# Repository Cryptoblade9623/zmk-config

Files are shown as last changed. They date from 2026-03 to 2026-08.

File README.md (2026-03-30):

Introduction
This is an ergonomic split keyboard that I designed to match the shape of my hands.
It is designed this way to hopefully reduce strain on my wrists and hands when typing.
I like making stuff.
I also just think that split keyboards are cool.
It uses the Seeeduino XIAO BLE nRF52840.
It has bluetooth communication capabilities and has a USB-C port.

Images

Above is my Split keyboard design on Fusion360.

Above is my PCB design.

Above is the root sheet for the schematics.


Above are the left then right schematics sheets.

Status
I have designed everything (hopefully) like the firmware, PCB and schematics.
I have also created the BOM.
I will start assembly when it is approved and i buy the parts needed.

Assembly instructions
1. Solder the diodes and hall sensors.
2. Solder the male header pins onto the seeeduino.
3. Link the seeeduino to the firmware on ZMK.
4. Solder the other side of the male header pins onto the PCB.
5. Screw the stabilizers into the PCB.
6. Solder the wires of the battery to the bat pins of the microcontroller and the sliding switch.
7. Place the battery into the small cavity in between the case and where the PCb is meant to go.
8. Screw the sliding switch into the side.
9. Insert the brass threaded insert into the 3d printed case in the middle and on the rim by heating the inserts and pushing them in.
10. Screw in the five mounting screw in to the middle.
11. Place the PCB on top and screw the black screws in.
12. Glue the magnets into the holes in the 3d printed case.
13. Click the key Switches into the plate.
14. Screw the plate on the bigger portion of the case.
15. Click the keycaps into place.
16. Repeat for both halves.
17. Pair both the halves together.
18. Test the keyboard.
I have not actually built the keyboard yet.

BOM
Name	                     Purpose	                          Units Total	            Total (USD)    	Distributor
Male header pin row        For soldering Seeeduino to PCB    	1     	                $1.31	          AliExpress
Battery	                   To supply power                   	1	Pair                  $9.18	          AliExpress
Screws                   	 Secure keyboard parts	            1 Pack	                $1.31	          AliExpress
Mounting screws	           Secure PCB in place	              1 Pack	                $0.74	          AliExpress
Threaded insert	           Housing for screws               	1 Pack                	$1.64	          AliExpress
PCB	                       Main circuit board               	1 Pack                	$14.38	        JLCPCB
Diodes	                   Direct current one way            	1 Pack	                $5.57	          AliExpress
Hall sensors	             Magnetic detection 	              3 Packs	                $11.51   	      AliExpress
Magnets                    Connect halves together	          1 Pack                	$1.31         	AliExpress
Sliding Switches           Power On/Off                     	1	Pack                  $5.10          	Amazon
Stabilizers                Support for larger keycaps	        2	                      $4.44	          AliExpress
Key Switches	             Register key strokes	              1 Pack                	$45.27         	AliExpress
Seeeduino (2pcs)         	 Main controllers	                  1 Pair	                $38.42        	AliExpress
Keycaps	                   Key labels	                        1 Set                 	$16.79	        AliExpress

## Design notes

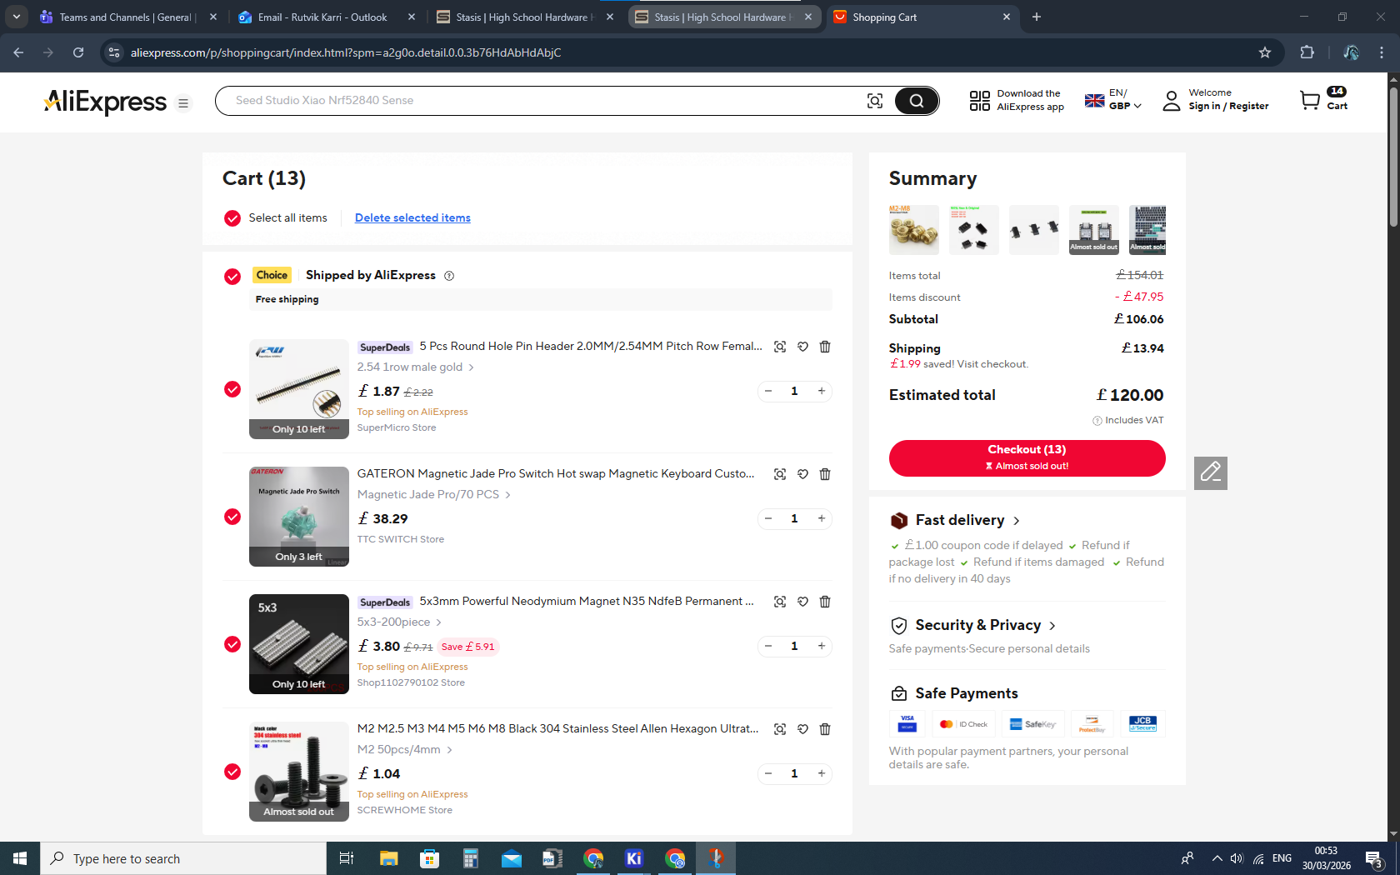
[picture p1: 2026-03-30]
Kicad Files/alicartfinal.png

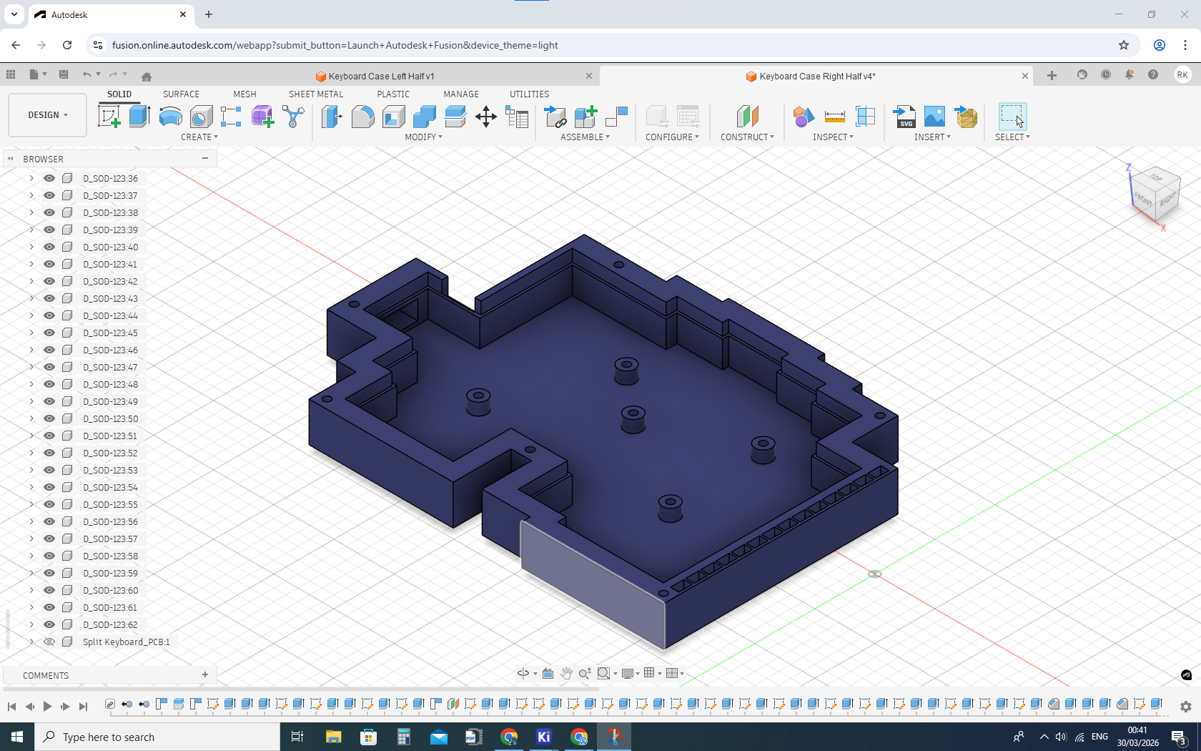
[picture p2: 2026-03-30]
Kicad Files/case right2.png

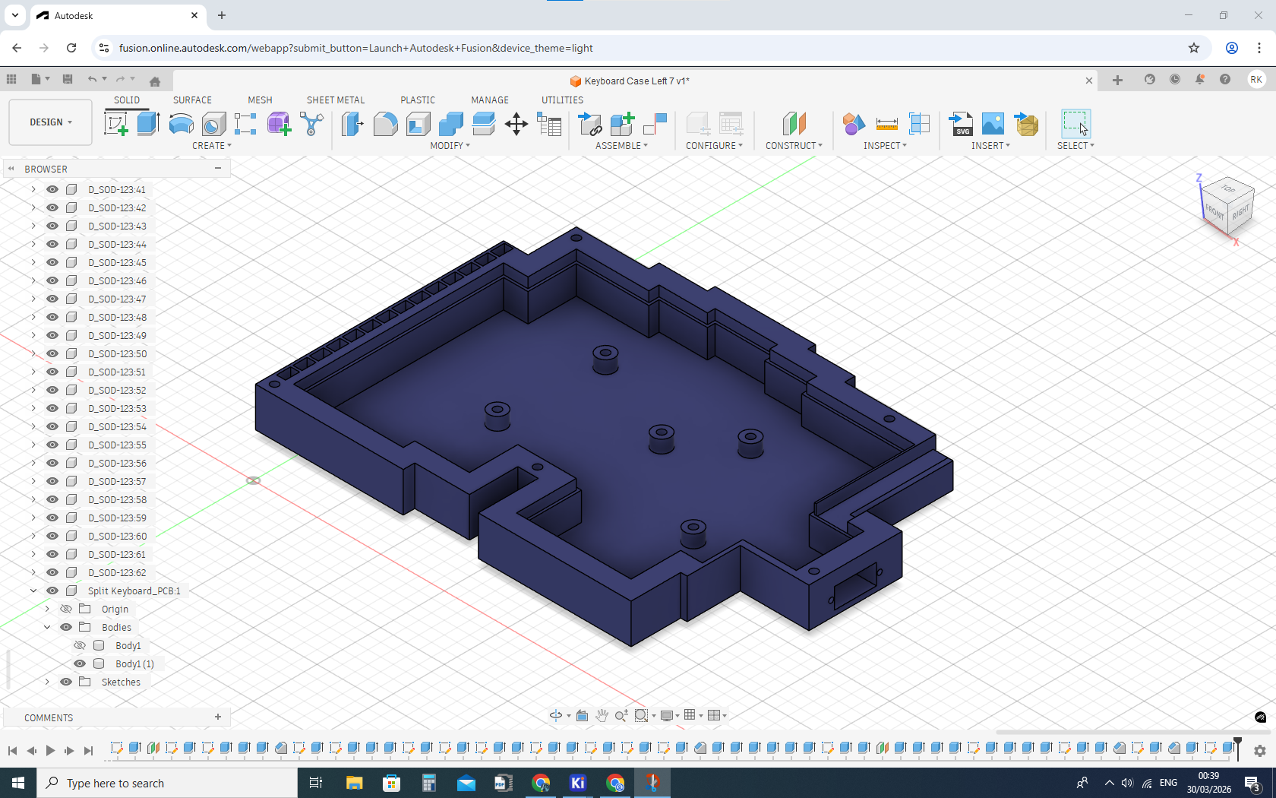
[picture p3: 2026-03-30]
Kicad Files/case left2.png

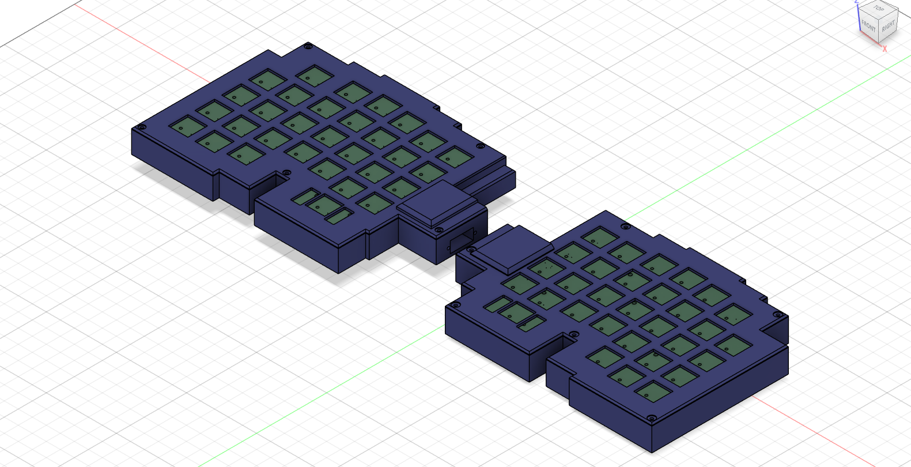
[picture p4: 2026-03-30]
Kicad Files/Both halves split custom keeb.png

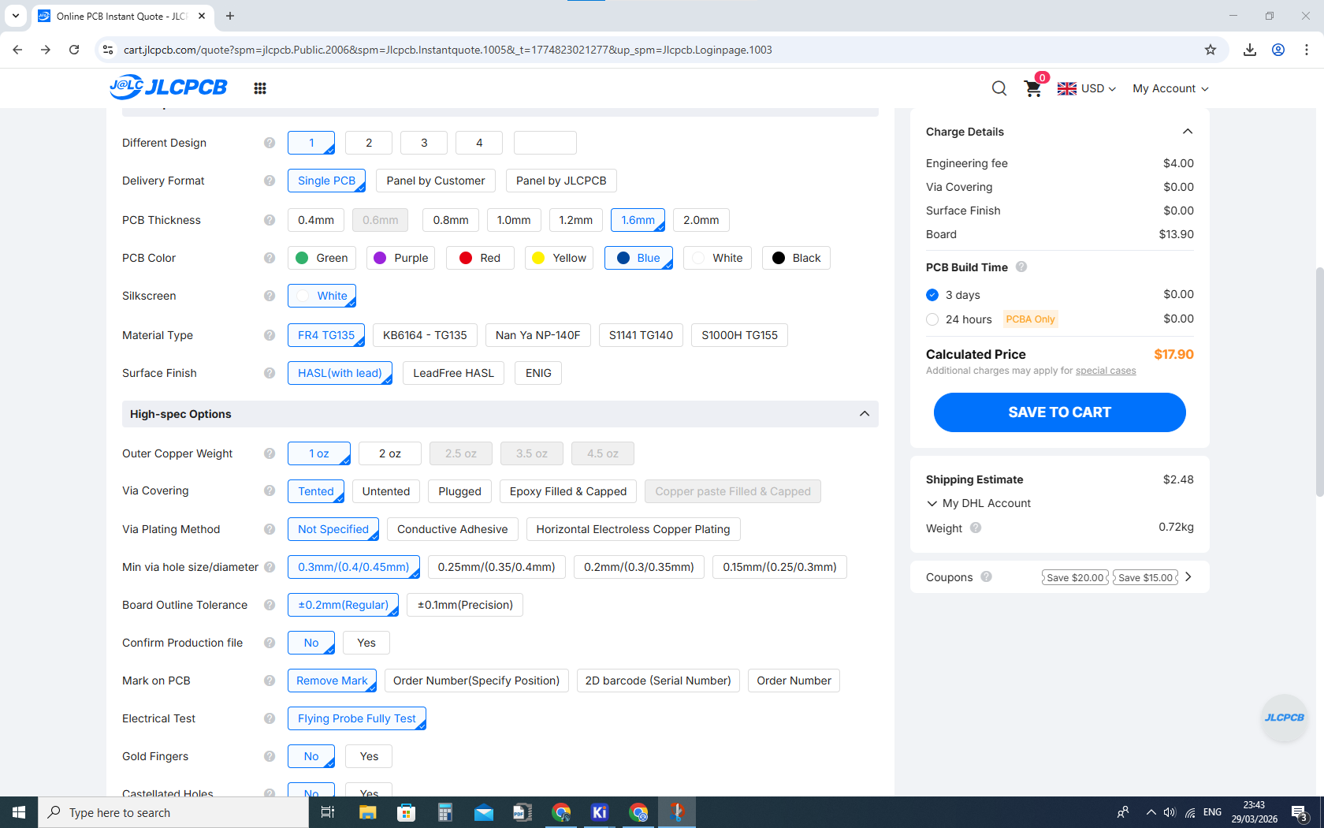
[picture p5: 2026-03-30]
Kicad Files/jlc cart new bottom.png

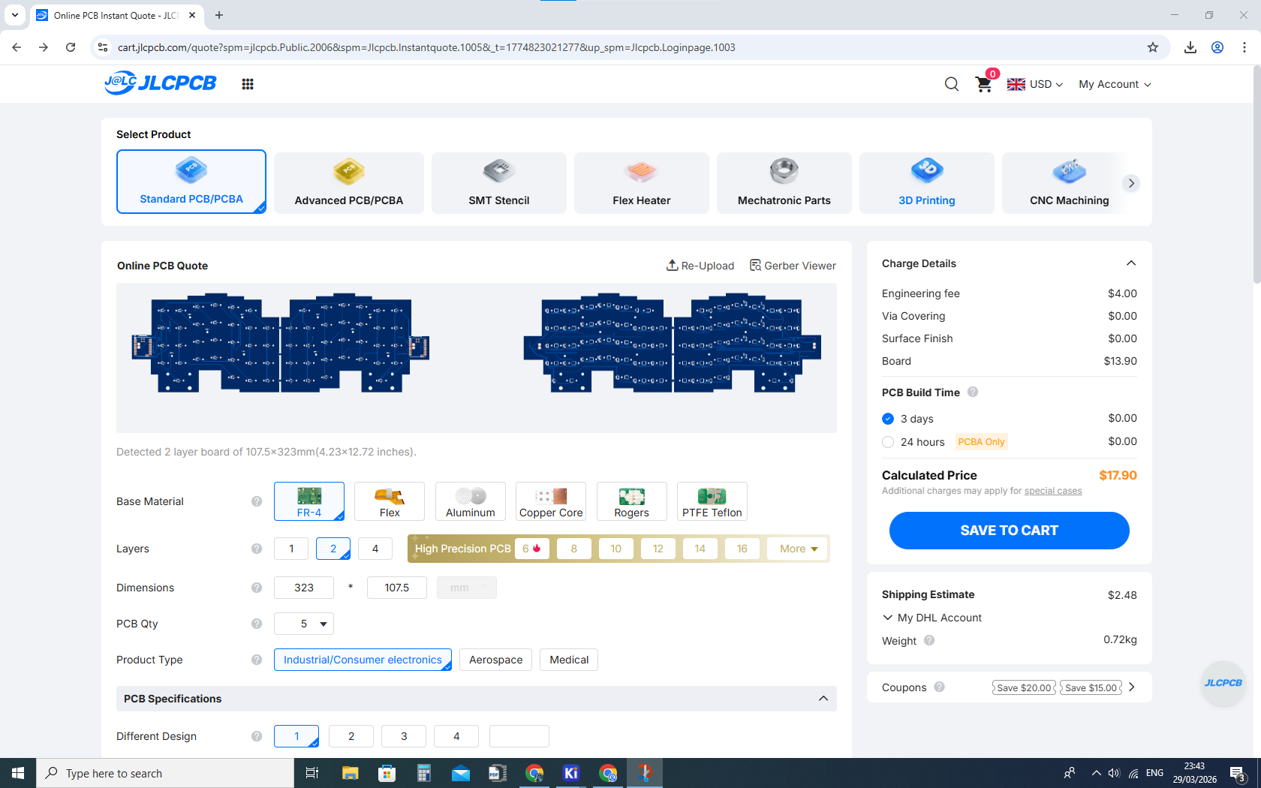
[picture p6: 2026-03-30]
Kicad Files/jlc cart new top.png

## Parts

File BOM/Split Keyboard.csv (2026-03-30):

Reference | Qty | Value | DNP | Exclude from BOM | Exclude from Board | Footprint | Datasheet
D1,D2,D3,D4,D5,D6,D7,D8,D9,D10,D11,D12,D13,D14,D15,D16,D17,D18,D19,D20,D21,D22,D23,D24,D25,D26,D27,D28,D29,D30,D31,D32,D33,D34,D35,D36,D37,D38,D39,D40,D41,D42,D51,D52,D53,D54,D55,D56,D57,D58,D59,D60,D61,D62,D63,D64,D65,D66,D67,D68,D69,D70 | 62 | D |  |  |  | Diode_SMD:D_SOD-123 | ~
H1,H3,H5 | 3 | MountingHole |  | Excluded from BOM |  | Panelization:MouseBite-Slot_2.0x2.0mm_inset_D0.5mm_P0.85mm_4h_Trace | ~
S1,S2 | 2 | MX_stab |  |  |  | marbastlib-mx:STAB_MX_2u
SW1,SW2,SW3,SW4,SW5,SW6,SW7,SW8,SW10,SW11,SW12,SW14,SW15,SW16,SW17,SW18,SW19,SW20,SW21,SW22,SW23,SW24,SW25,SW26,SW27,SW28,SW29,SW30,SW31,SW32,SW33,SW34,SW35,SW36,SW37,SW38,SW39,SW40,SW41,SW42,SW51,SW52,SW53,SW54,SW55,SW56,SW57,SW58,SW59,SW60,SW61,SW62,SW63,SW64,SW65,SW66,SW67,SW68,SW69,SW70 | 60 | SW_Push |  |  |  | marbastlib-he:SW_MX_HE_0deg_1u | ~
SW9,SW13 | 2 | SW_Push |  |  |  | marbastlib-he:SW_MX_HE_0deg_1.5u | ~
U1,U2 | 2 | Seeeduino Xiao nRF52840 |  | Excluded from BOM |  | Modified xioa:modified-XIAO-nRF52840-SMD

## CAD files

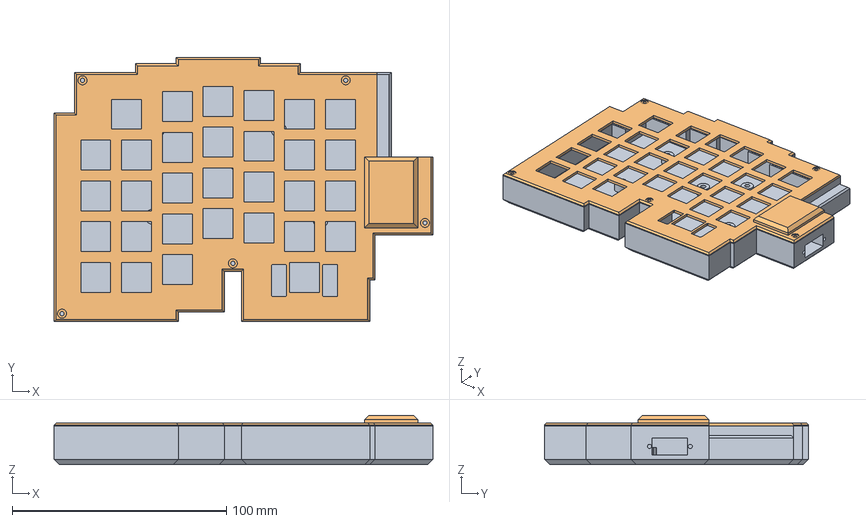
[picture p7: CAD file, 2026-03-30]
Kicad Files/Keyboard Case Left Half.step
177.1 x 123.5 x 23.0 mm
SOT-23 x 60
D_SOD-123 x 62
Split Keyboard_PCB

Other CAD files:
Kicad Files/Keyboard Case Right Half.step
Kicad Files/Keyboard Case Left Half.stl
Kicad Files/Keyboard Case Right Half.stl

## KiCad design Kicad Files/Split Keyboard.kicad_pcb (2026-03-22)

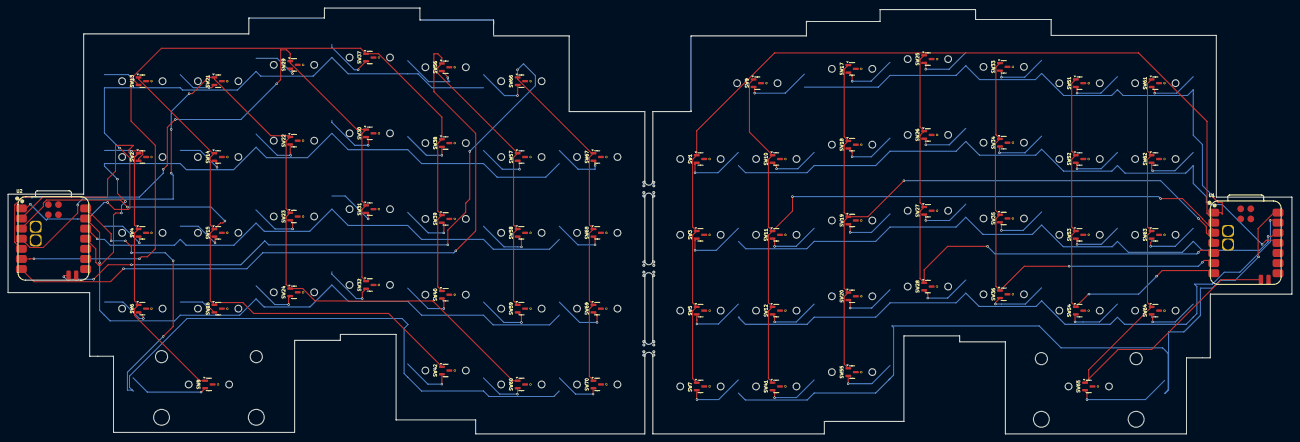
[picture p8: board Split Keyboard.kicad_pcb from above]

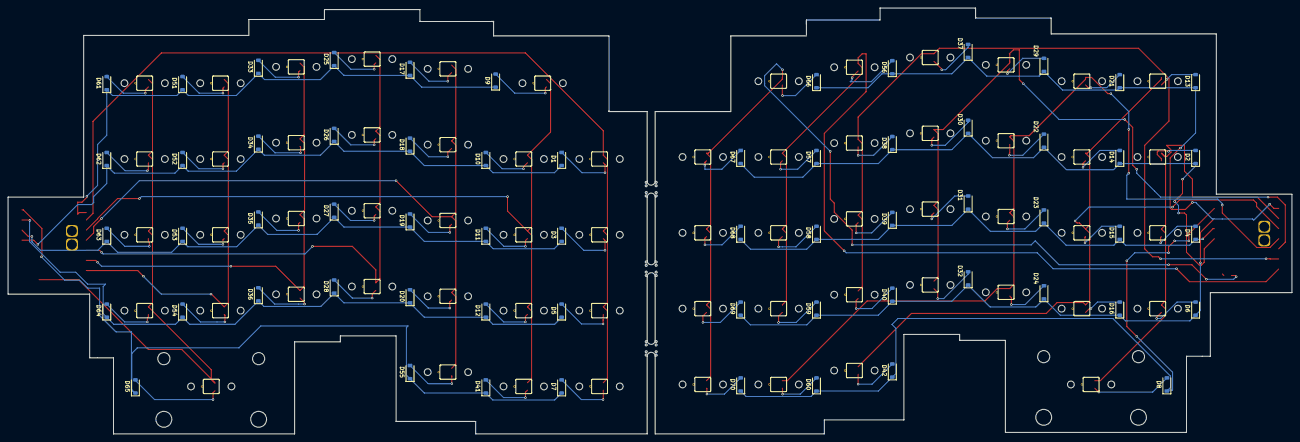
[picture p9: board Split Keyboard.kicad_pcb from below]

Board: 2 copper layers, 322.6 x 107.0 mm, 131 parts (62 on the bottom side), 87 nets.

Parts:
D1, D2, D3, D4, D5, D6, D7, D8, D9, D10, D11, D12, D13, D14, D15, D16, D17, D18, D19, D20, D21, D22, D23, D24, D25, D26, D27, D28, D29, D30, D31, D32, D33, D34, D35, D36, D37, D38, D39, D40, D41, D42, D51, D52, D53, D54, D55, D56, D57, D58, D59, D60, D61, D62, D63, D64, D65, D66, D67, D68, D69, D70: D; D_SOD-123
H1, H3, H5: MountingHole; MouseBite-Slot_2.0x2.0mm_inset_D0.5mm_P0.85mm_4h_Trace
S1, S2: MX_stab; STAB_MX_2u
SW1, SW2, SW3, SW4, SW5, SW6, SW7, SW8, SW10, SW11, SW12, SW14, SW15, SW16, SW17, SW18, SW19, SW20, SW21, SW22, SW23, SW24, SW25, SW26, SW27, SW28, SW29, SW30, SW31, SW32, SW33, SW34, SW35, SW36, SW37, SW38, SW39, SW40, SW41, SW42, SW51, SW52, SW53, SW54, SW55, SW56, SW57, SW58, SW59, SW60, SW61, SW62, SW63, SW64, SW65, SW66, SW67, SW68, SW69, SW70: SW_Push; SW_MX_HE_0deg_1u
SW9, SW13: SW_Push; SW_MX_HE_0deg_1.5u
U1, U2: Seeeduino Xiao nRF52840; modified-XIAO-nRF52840-SMD

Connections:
/Left/COL0: SW1.1, SW3.1, SW5.1, SW7.1, U1.2 (P0.03)
/Left/COL1: SW9.1, SW10.1, SW11.1, SW12.1, SW41.1, U1.3 (P0.28)
/Left/COL2: SW17.1, SW18.1, SW19.1, SW20.1, SW55.1, U1.4 (P0.29)
/Left/COL3: SW25.1, SW26.1, SW27.1, SW28.1, U1.5 (P0.04)
/Left/COL4: SW33.1, SW34.1, SW35.1, SW36.1, U1.6 (P0.05)
/Left/COL5: SW51.1, SW52.1, SW53.1, SW54.1, U1.7 (P1.11)
/Left/COL6: SW61.1, SW62.1, SW63.1, SW64.1, SW65.1, U1.17 (P0.09)
/Left/ROW0: D9.1 (K), D17.1 (K), D25.1 (K), D33.1 (K), D51.1 (K), D61.1 (K), U1.1 (P0.02)
/Left/ROW1: D1.1 (K), D10.1 (K), D18.1 (K), D26.1 (K), D34.1 (K), D52.1 (K), D62.1 (K), U1.11 (P1.15)
/Left/ROW2: D3.1 (K), D11.1 (K), D19.1 (K), D27.1 (K), D35.1 (K), D53.1 (K), D63.1 (K), U1.12 (P1.14)
/Left/ROW3: D5.1 (K), D12.1 (K), D20.1 (K), D28.1 (K), D36.1 (K), D54.1 (K), D64.1 (K), U1.13 (P1.13)
/Left/ROW4: D7.1 (K), D41.1 (K), D55.1 (K), D65.1 (K), U1.14 (P1.12)
/Right/COL0: SW2.1, SW4.1, SW6.1, SW8.1, U2.2 (P0.03)
/Right/COL1: SW13.1, SW14.1, SW15.1, SW16.1, SW42.1, U2.3 (P0.28)
/Right/COL2: SW21.1, SW22.1, SW23.1, SW24.1, SW60.1, U2.4 (P0.29)
/Right/COL3: SW29.1, SW30.1, SW31.1, SW32.1, U2.5 (P0.04)
/Right/COL4: SW37.1, SW38.1, SW39.1, SW40.1, U2.6 (P0.05)
/Right/COL5: SW56.1, SW57.1, SW58.1, SW59.1, U2.7 (P1.11)
/Right/COL6: SW66.1, SW67.1, SW68.1, SW69.1, SW70.1, U2.17 (P0.09)
/Right/ROW0: D13.1 (K), D21.1 (K), D29.1 (K), D37.1 (K), D56.1 (K), D66.1 (K), U2.1 (P0.02)
/Right/ROW1: D2.1 (K), D14.1 (K), D22.1 (K), D30.1 (K), D38.1 (K), D57.1 (K), D67.1 (K), U2.11 (P1.15)
/Right/ROW2: D4.1 (K), D15.1 (K), D23.1 (K), D31.1 (K), D39.1 (K), D58.1 (K), D68.1 (K), U2.12 (P1.14)
/Right/ROW3: D6.1 (K), D16.1 (K), D24.1 (K), D32.1 (K), D40.1 (K), D59.1 (K), D69.1 (K), U2.13 (P1.13)
/Right/ROW4: D8.1 (K), D42.1 (K), D60.1 (K), D70.1 (K), U2.14 (P1.12)
GND: U1.9 (GND), U2.9 (GND)
unnamed: D1.2 (A), SW1.2
unnamed: D2.2 (A), SW2.2
unnamed: D3.2 (A), SW3.2
unnamed: D4.2 (A), SW4.2
unnamed: D5.2 (A), SW5.2
unnamed: D6.2 (A), SW6.2
unnamed: D7.2 (A), SW7.2
unnamed: D8.2 (A), SW8.2
unnamed: D9.2 (A), SW9.2
unnamed: D10.2 (A), SW10.2
unnamed: D11.2 (A), SW11.2
unnamed: D12.2 (A), SW12.2
unnamed: D13.2 (A), SW13.2
unnamed: D14.2 (A), SW14.2
unnamed: D15.2 (A), SW15.2
unnamed: D16.2 (A), SW16.2
unnamed: D17.2 (A), SW17.2
unnamed: D18.2 (A), SW18.2
unnamed: D19.2 (A), SW19.2
unnamed: D20.2 (A), SW20.2
unnamed: D21.2 (A), SW21.2
unnamed: D22.2 (A), SW22.2
unnamed: D23.2 (A), SW23.2
unnamed: D24.2 (A), SW24.2
unnamed: D25.2 (A), SW25.2
unnamed: D26.2 (A), SW26.2
unnamed: D27.2 (A), SW27.2
unnamed: D28.2 (A), SW28.2
unnamed: D29.2 (A), SW29.2
unnamed: D30.2 (A), SW30.2
unnamed: D31.2 (A), SW31.2
unnamed: D32.2 (A), SW32.2
unnamed: D33.2 (A), SW33.2
unnamed: D34.2 (A), SW34.2
unnamed: D35.2 (A), SW35.2
unnamed: D36.2 (A), SW36.2
unnamed: D37.2 (A), SW37.2
unnamed: D38.2 (A), SW38.2
unnamed: D39.2 (A), SW39.2
unnamed: D40.2 (A), SW40.2
unnamed: D41.2 (A), SW41.2
unnamed: D42.2 (A), SW42.2
unnamed: D51.2 (A), SW51.2
unnamed: D52.2 (A), SW52.2
unnamed: D53.2 (A), SW53.2
unnamed: D54.2 (A), SW54.2
unnamed: D55.2 (A), SW55.2
unnamed: D56.2 (A), SW56.2
unnamed: D57.2 (A), SW57.2
unnamed: D58.2 (A), SW58.2
unnamed: D59.2 (A), SW59.2
unnamed: D60.2 (A), SW60.2
unnamed: D61.2 (A), SW61.2
unnamed: D62.2 (A), SW62.2
unnamed: D63.2 (A), SW63.2
unnamed: D64.2 (A), SW64.2
unnamed: D65.2 (A), SW65.2
unnamed: D66.2 (A), SW66.2
unnamed: D67.2 (A), SW67.2
unnamed: D68.2 (A), SW68.2
unnamed: D69.2 (A), SW69.2
unnamed: D70.2 (A), SW70.2

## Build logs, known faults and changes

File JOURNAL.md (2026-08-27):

# 3/30/2026 12 PM - BOM and CASE

_Time spent: 2h_

i refined the bom so that it was under 150 bits but i couldnt go any lower

I also updated the case of both halves











# 3/24/2026 11 PM - Case

_Time spent: 3h_

I finished both halves of the case by manually adding all the holes in the plate under the keycaps.I added holes for the USBC ports, screws and sliding switches. unfortunately I can't add any images as my computer keeps on crashing but i will have it by wednesday morning just tell me who to send them to. Please don't disqualify me!








# 3/22/2026 7 PM - Case

_Time spent: 4h_

I got started on the left half of the keyboard case and finished  a quarter of it. i also finalised the BOM.








# 3/22/2026 10 AM - ZMK Firmware

_Time spent: 3h_

I finished  the firmware in zmk and linked my repo to the project.








# 3/19/2026 9 PM - Wiring

_Time spent: 3h_






Finished PCB and started making the repo.





# 3/17/2026 9 PM - PCB

_Time spent: 0.5h_

I arrnged it to fit my hand shape and size using a placing software with my tablet. I also chnged some footprints, amounts, and sizes of the keys.








# 3/16/2026 9 PM - Schematics and some of the PCB

_Time spent: 2.5h_

I updated the schematics and PCB so that each half will have 34 keys. I put all the push switches in place on the left side, although i failed to record the full sizes of all the keys.







# 3/15/2026 7 PM - Schematics and some of the PCB

_Time spent: 5h_





I worked on creating the schematics and once I finished that I added the sutom footprints and started te PCB. I arranged the push switches and xiao for the left half.




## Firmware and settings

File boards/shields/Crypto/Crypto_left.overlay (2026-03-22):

/ {
    chosen {
        zmk,kscan = &kscan0;
    };

    kscan0: kscan {
        compatible = "zmk,kscan-gpio-matrix";
        wakeup-source;
        diode-direction = "col2row";

        col-gpios
            = <&xiao_d 1 GPIO_ACTIVE_HIGH> // COL0 (Pad 2)
            , <&xiao_d 2 GPIO_ACTIVE_HIGH> // COL1 (Pad 3)
            , <&xiao_d 3 GPIO_ACTIVE_HIGH> // COL2 (Pad 4)
            , <&xiao_d 4 GPIO_ACTIVE_HIGH> // COL3 (Pad 5)
            , <&xiao_d 5 GPIO_ACTIVE_HIGH> // COL4 (Pad 6)
            , <&xiao_d 6 GPIO_ACTIVE_HIGH> // COL5 (Pad 7)
            , <&gpio0 9 GPIO_ACTIVE_HIGH>  // COL6 (Pad 17 - The "Secret" 12th pin)
            ;

        row-gpios
            = <&xiao_d 0  (GPIO_ACTIVE_HIGH | GPIO_PULL_DOWN)> // ROW0 (Pad 1)
            , <&xiao_d 7  (GPIO_ACTIVE_HIGH | GPIO_PULL_DOWN)> // ROW1 (Pad 11)
            , <&xiao_d 8  (GPIO_ACTIVE_HIGH | GPIO_PULL_DOWN)> // ROW2 (Pad 12)
            , <&xiao_d 9  (GPIO_ACTIVE_HIGH | GPIO_PULL_DOWN)> // ROW3 (Pad 13)
            , <&xiao_d 10 (GPIO_ACTIVE_HIGH | GPIO_PULL_DOWN)> // ROW4 (Pad 14)
            ;
    };
};

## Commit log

2026-03-22 Create Schematics
2026-03-30 Rename Split Keyboard-all-pos.csv to BOM/Split Keyboard-all-pos.csv
    [Split Keyboard-all-pos.csv]
2026-03-30 Rename Split Keyboard-bottom-pos.csv to BOM/Split Keyboard-bottom-pos.csv
    [Split Keyboard-bottom-pos.csv]
2026-03-30 Rename Split Keyboard-top-pos.csv to BOM/lit Keyboard-top-pos.csv
    [lit Keyboard-top-pos.csv]
2026-03-30 Rename lit Keyboard-top-pos.csv to Split Keyboard-top-pos.csv
    [Split Keyboard-top-pos.csv]
2026-03-30 Rename Split Keyboard.csv to BOM/Split Keyboard.csv
    [Split Keyboard.csv]
2026-03-30 Create Footprints
2026-03-30 Create slots
2026-08-27 Delete journal entry for 8/18/2026
    Removed entry about soldering progress on keyboard.
